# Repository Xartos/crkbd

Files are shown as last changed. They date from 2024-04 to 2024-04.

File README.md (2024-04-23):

# Fork purpose

The purpose of this fork is to replace the audio jack `ST-0277D00-052-142` for the v4 model and replace it with the `PJ-606-6A`

# Corne keyboard

The Corne keyboard is a split keyboard with 3x6 column staggered keys
and 3 thumb keys, based on [Helix](https://github.com/MakotoKurauchi/helix).
Crkbd stands for Corne Keyboard.

v4

## Latest versions
- corne-cherry: for Cherry MX compatible switches

  - v4 Hotswappable ([JP](docs/corne-cherry/v4/buildguide_jp.md)/[EN](docs/corne-cherry/v4/buildguide_en.md))
  - v4 Soldering (will be released)
- corne-chocolate: for Kailh choc v1 and v2 switches
  - v4 Hotswappable ([JP](docs/corne-chocolate/v4/buildguide_jp.md)/[EN](docs/corne-chocolate/v4/buildguide_en.md)):
  - v4 Soldering (will be released)

## Old versions

- corne-classic: for Cherry MX compatible switches 
  - v1 Soldering: ([JP](docs/corne-classic/buildguide_jp.md)/[EN](docs/corne-classic/buildguide_en.md))
- corne-cherry: for Cherry MX compatible switches
  - v2 Hotswappable: ([JP](docs/corne-cherry/v2/buildguide_jp.md)/[EN](docs/corne-cherry/v2/buildguide_en.md))
  - v2 Hotswappable tilting version: ([tilting, JP](docs/corne-cherry/v2/buildguide_tilting_tenting_plate_jp.md)/[tilting, EN](docs/corne-cherry/v2/buildguide_tilting_tenting_plate_en.md)):
  - v3 Hotswappable: ([JP](docs/corne-cherry/v3/buildguide_jp.md)/[EN](docs/corne-cherry/v3/buildguide_en.md))
- corne-chocolate: for Kailh choc v1 switches
  - v2 Hotswappable: ([JP](docs/corne-chocolate/v2/buildguide_jp.md)/[EN](docs/corne-chocolate/v2/buildguide_en.md)):
- corne-light: for easy build with a simple PCB
  - v1 Soldering: ([JP](docs/corne-light/v1/buildguide_jp.md)/[EN](docs/corne-light/v1/buildguide_en.md)):
  - v2 Soldering: ([JP](docs/corne-light/v2/buildguide_low_edition_jp.md)/[EN](docs/corne-light/v2/buildguide_low_edition_en.md)):

## Images

### Cherry
corne-cherry



### Chocolate
corne-chocolate



### Drawing
sketche

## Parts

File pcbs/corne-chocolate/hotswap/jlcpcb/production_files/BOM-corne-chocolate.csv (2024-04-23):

Designator | Footprint | Quantity | Value | LCSC Part #
C1, C2, rC1, rC2 | 0402 | 4 | 27p
C10, C12, C13, C14, C15, C3, C4, C7, C9, rC10, rC12, rC13, rC14, rC15, rC3, rC4, rC7, rC9 | 0402 | 18 | 100n
C11, C6, rC11, rC6 | 0402 | 4 | 10u
C16, C5, C8, rC16, rC5, rC8 | 0402 | 6 | 1u
D1, rD1 | D_SOD-523 | 2 | 1N4148WT | C232841
EXLED1, EXLED2, LED1, LED10, LED11, LED12, LED13, LED14, LED15, LED16, LED17, LED18, LED19, LED2, LED20, LED21, LED3, LED4, LED5, LED6, LED7, LED8, LED9, rEXLED1, rEXLED2, rLED1, rLED10, rLED11, rLED12, rLED13, rLED14, rLED15, rLED16, rLED17, rLED18, rLED19, rLED2, rLED20, rLED21, rLED3, rLED4, rLED5, rLED6, rLED7, rLED8, rLED9 | YS-SK6812MINI-E | 46 | YS-SK6812MINI-E | C5149201
EXSW1, EXSW2, rEXSW1, rEXSW2 | keyswitch_choc12_hotswap_1u_rotary_encoder_ec12 | 4 | RotaryEncoder_Switch | C5333465
F1, rF1 | 0603 | 2 | BSMD0603-050-12V | C2844464
J1, rJ1 | TYPE-C-31-M-13C | 2 | TYPE-C-31-M-13C | C2848620
J2, rJ2 | PJ-606-6A | 2 | PJ-606-6A | C145806
R1, R2, rR1, rR2 | 0402 | 4 | 5.1k
R3, R6, rR3, rR6 | 0402 | 4 | 1k
R4, R5, rR4, rR5 | 0402 | 4 | 27
R7, rR7 | 0402 | 2 | 10k
SMDSW1, SMDSW2, rSMDSW1, rSMDSW2 | TS-1088R-02026 | 4 | TS-1088R-02026 | C455280
SW1, rSW1 | keyswitch_choc12_hotswap_1.5u | 2 | SW_Push | C5333465
SW10, SW11, SW12, SW13, SW14, SW15, SW16, SW17, SW18, SW19, SW2, SW20, SW21, SW3, SW4, SW5, SW6, SW7, SW8, SW9, rSW10, rSW11, rSW12, rSW13, rSW14, rSW15, rSW16, rSW17, rSW18, rSW19, rSW2, rSW20, rSW21, rSW3, rSW4, rSW5, rSW6, rSW7, rSW8, rSW9 | keyswitch_choc12_hotswap_1u | 40 | SW_Push | C5333465
U1, rU1 | QFN-56-1EP_7x7mm_P0.4mm_EP3.2x3.2mm | 2 | RP2040 | C2040
U2, rU2 | SOT-223-3_TabPin2 | 2 | NCP1117LPST33T3G | C146799
U3, rU3 | USON-10_2.5x1.0mm_P0.5mm | 2 | TPD4E05U06DQAR | C138714
U4, rU4 | SOIC-8_5.23x5.23mm_P1.27mm | 2 | W25Q128JVSIQ | C113767
Y1, rY1 | Crystal_SMD_3225-4Pin_3.2x2.5mm | 2 | 12MHz 18pF | C91749
ZD1, rZD1 | D_SOD-523 | 2 | ESD5Z5V0C | C2901325

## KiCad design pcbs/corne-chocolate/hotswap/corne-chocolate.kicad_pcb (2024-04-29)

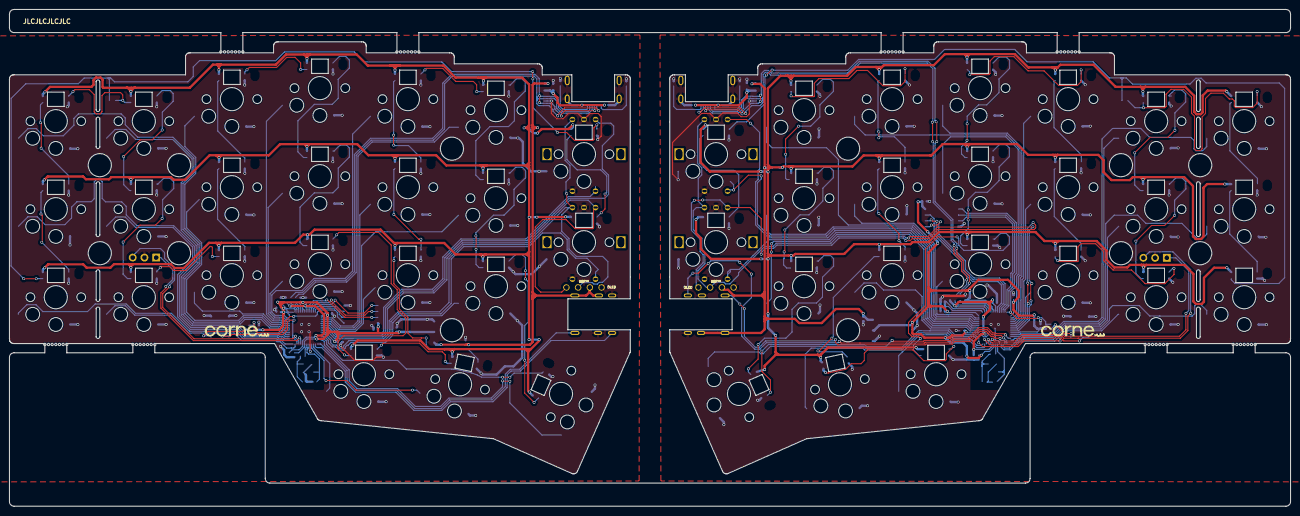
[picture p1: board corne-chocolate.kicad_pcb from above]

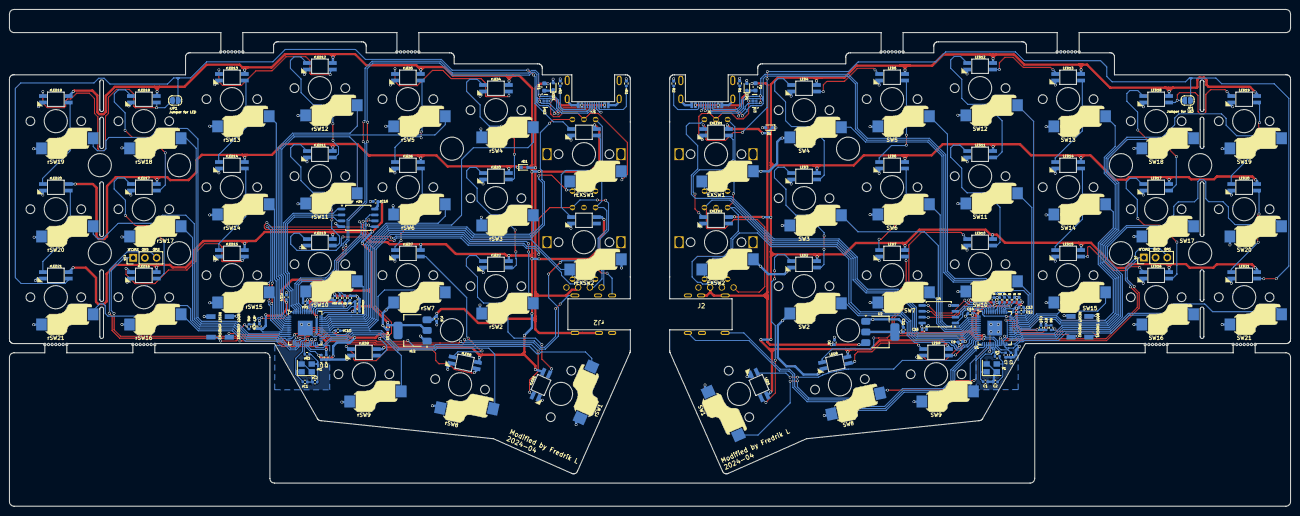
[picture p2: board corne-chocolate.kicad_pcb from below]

Board: 2 copper layers, 277.2 x 107.5 mm, 176 parts (166 on the bottom side), 152 nets.

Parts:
BT1, BT2, BT3, BT4: Breakaway Tabs; Breakaway_Tabs
C1, C2: 27p; C_0402_1005Metric
C3, C4, C7, C9, C10, C12, C13, C14, C15: 100n; C_0402_1005Metric
C5, C8, C16: 1u; C_0402_1005Metric
C6, C11: 10u; C_0402_1005Metric
D1: 1N4148WT; D_SOD-523
EXLED1, EXLED2: YS-SK6812MINI-E
EXSW1, EXSW2: RotaryEncoder_Switch; keyswitch_choc12_hotswap_1u_rotary_encoder_ec12
F1: BSMD0603-050-12V; Fuse_0603_1608Metric
J1: TYPE-C-31-M-13C
J2: PJ-606-6A
J3: Conn_01x04; OLED
J4: Conn_01x03; PinHeader_1x03_P2.54mm_Vertical
JP1: SolderJumper_2_Bridged; SolderJumper-2_P1.3mm_Open_RoundedPad1.0x1.5mm
LED1, LED2, LED3, LED4, LED5, LED6, LED7, LED8, LED9, LED10, LED11, LED12, LED13, LED14, LED15, LED16, LED17, LED18, LED19, LED20, LED21: YS-SK6812MINI-E
R1, R2: 5.1k; R_0402_1005Metric
R3, R6: 1k; R_0402_1005Metric
R4, R5: 27; R_0402_1005Metric
R7: 10k; R_0402_1005Metric
SMDSW1, SMDSW2: TS-1088R-02026
SW1: SW_Push; keyswitch_choc12_hotswap_1.5u
SW2, SW3, SW4, SW5, SW6, SW7, SW8, SW9, SW10, SW11, SW12, SW13, SW14, SW15, SW16, SW17, SW18, SW19, SW20, SW21: SW_Push; keyswitch_choc12_hotswap_1u
U1: RP2040; QFN-56-1EP_7x7mm_P0.4mm_EP3.2x3.2mm
U2: NCP1117LPST33T3G; SOT-223-3_TabPin2
U3: TPD4E05U06DQAR; USON-10_2.5x1.0mm_P0.5mm
U4: W25Q128JVSIQ; SOIC-8_5.23x5.23mm_P1.27mm
Y1: 12MHz 18pF; Crystal_SMD_3225-4Pin_3.2x2.5mm
ZD1: ESD5Z5V0C; D_SOD-523
rBT1, rBT2, rBT3, rBT4: Breakaway Tabs; Breakaway_Tabs
rC1, rC2: 27p; C_0402_1005Metric
rC3, rC4, rC7, rC9, rC10, rC12, rC13, rC14, rC15: 100n; C_0402_1005Metric
rC5, rC8, rC16: 1u; C_0402_1005Metric
rC6, rC11: 10u; C_0402_1005Metric
rD1: 1N4148WT; D_SOD-523
rEXLED1, rEXLED2: YS-SK6812MINI-E
rEXSW1, rEXSW2: RotaryEncoder_Switch; keyswitch_choc12_hotswap_1u_rotary_encoder_ec12
rF1: BSMD0603-050-12V; Fuse_0603_1608Metric
rJ1: TYPE-C-31-M-13C
rJ2: PJ-606-6A
rJ3: Conn_01x04; OLED
rJ4: Conn_01x03; PinHeader_1x03_P2.54mm_Vertical
rJP1: SolderJumper_2_Bridged; SolderJumper-2_P1.3mm_Open_RoundedPad1.0x1.5mm
rLED1, rLED2, rLED3, rLED4, rLED5, rLED6, rLED7, rLED8, rLED9, rLED10, rLED11, rLED12, rLED13, rLED14, rLED15, rLED16, rLED17, rLED18, rLED19, rLED20, rLED21: YS-SK6812MINI-E
rR1, rR2: 5.1k; R_0402_1005Metric
rR3, rR6: 1k; R_0402_1005Metric
rR4, rR5: 27; R_0402_1005Metric
rR7: 10k; R_0402_1005Metric
rSMDSW1, rSMDSW2: TS-1088R-02026
rSW1: SW_Push; keyswitch_choc12_hotswap_1.5u
rSW2, rSW3, rSW4, rSW5, rSW6, rSW7, rSW8, rSW9, rSW10, rSW11, rSW12, rSW13, rSW14, rSW15, rSW16, rSW17, rSW18, rSW19, rSW20, rSW21: SW_Push; keyswitch_choc12_hotswap_1u
rU1: RP2040; QFN-56-1EP_7x7mm_P0.4mm_EP3.2x3.2mm
rU2: NCP1117LPST33T3G; SOT-223-3_TabPin2
rU3: TPD4E05U06DQAR; USON-10_2.5x1.0mm_P0.5mm
rU4: W25Q128JVSIQ; SOIC-8_5.23x5.23mm_P1.27mm
rY1: 12MHz 18pF; Crystal_SMD_3225-4Pin_3.2x2.5mm
rZD1: ESD5Z5V0C; D_SOD-523

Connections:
+1V1: C3.1, C4.1, C5.1, U1.23 (DVDD), U1.45 (VREG_VOUT), U1.50 (DVDD)
+1V1R: rC3.1, rC4.1, rC5.1, rU1.23 (DVDD), rU1.45 (VREG_VOUT), rU1.50 (DVDD)
+3V3: C7.1, C8.1, C9.1, C10.1, C11.1, C12.1, C13.1, C14.1, C15.1, C16.1, R7.2, U1.1 (IOVDD), U1.10 (IOVDD), U1.22 (IOVDD), U1.32 (GPIO21), U1.33 (IOVDD), U1.42 (IOVDD), U1.43 (ADC_AVDD), U1.44 (VREG_IN), U1.48 (USB_VDD), U1.49 (IOVDD), U2.2 (VO), U4.8 (VCC)
+3V3R: rC7.1, rC8.1, rC9.1, rC10.1, rC11.1, rC12.1, rC13.1, rC14.1, rC15.1, rC16.1, rR7.2, rU1.1 (IOVDD), rU1.10 (IOVDD), rU1.22 (IOVDD), rU1.33 (IOVDD), rU1.42 (IOVDD), rU1.43 (ADC_AVDD), rU1.44 (VREG_IN), rU1.48 (USB_VDD), rU1.49 (IOVDD), rU2.2 (VO), rU4.8 (VCC)
+5V: C6.1, D1.2 (A), F1.2, J2.T, J3.3, U2.3 (VI)
+5VR: rC6.1, rD1.2 (A), rF1.2, rJ2.T, rJ3.3, rU2.3 (VI)
/left/D+: J1.A6 (D+), J1.B6 (D+), R4.1, U3.1 (D1+), U3.4 (D2+), U3.7 (NC), U3.10 (NC)
/left/D-: J1.A7 (D-), J1.B7 (D-), R5.2, U3.2 (D1-), U3.5 (D2-), U3.6 (NC), U3.9 (NC)
/left/KEY1: SW1.1, U1.14 (GPIO11)
/left/KEY2: SW2.1, U1.12 (GPIO9)
/left/KEY3: SW3.1, U1.4 (GPIO2)
/left/KEY4: SW4.1, U1.2 (GPIO0)
/left/KEY5: SW5.1, U1.41 (GPIO29_ADC3)
/left/KEY6: SW6.1, U1.3 (GPIO1)
/left/KEY7: SW7.1, U1.5 (GPIO3)
/left/KEY8: SW8.1, U1.18 (GPIO15)
/left/KEY9: SW9.1, U1.17 (GPIO14)
/left/KEY10: SW10.1, U1.40 (GPIO28_ADC2)
/left/KEY11: SW11.1, U1.39 (GPIO27_ADC1)
/left/KEY12: SW12.1, U1.38 (GPIO26_ADC0)
/left/KEY13: SW13.1, U1.35 (GPIO23)
/left/KEY14: SW14.1, U1.36 (GPIO24)
/left/KEY15: SW15.1, U1.37 (GPIO25)
/left/KEY16: SW16.1, U1.27 (GPIO16)
/left/KEY17: SW17.1, U1.29 (GPIO18)
/left/KEY18: SW18.1, U1.31 (GPIO20)
/left/KEY19: SW19.1, U1.34 (GPIO22)
/left/KEY20: SW20.1, U1.30 (GPIO19)
/left/KEY21: SW21.1, U1.28 (GPIO17)
/left/KEYEX1: EXSW1.S2, U1.6 (GPIO4)
/left/KEYEX2: EXSW2.S2, U1.11 (GPIO8)
/left/LED: LED1.4 (DIN), U1.13 (GPIO10)
/left/QSPI_SCLK: U1.52 (QSPI_SCLK), U4.6 (CLK)
/left/QSPI_SD0: U1.53 (QSPI_SD0), U4.5 (DI(IO0))
/left/QSPI_SD1: U1.55 (QSPI_SD1), U4.2 (DO(IO1))
/left/QSPI_SD2: U1.54 (QSPI_SD2), U4.3 (IO2)
/left/QSPI_SD3: U1.51 (QSPI_SD3), U4.7 (IO3)
/left/QSPI_SS: R6.1, R7.1, U1.56 (QSPI_SS), U4.1 (~CS)
/left/RE0A: EXSW1.A, U1.7 (GPIO5)
/left/RE1A: EXSW2.A, J3.1, U1.8 (GPIO6)
/left/REB: EXSW1.B, EXSW2.B, J3.2, U1.9 (GPIO7)
/left/RX: J2.R1, U1.16 (GPIO13)
/left/SWCLK: J4.1, U1.24 (SWCLK)
/left/SWD: J4.3, U1.25 (SWD)
/left/TX: J2.R2, U1.15 (GPIO12)
/right/D+: rJ1.A6 (D+), rJ1.B6 (D+), rR4.1, rU3.1 (D1+), rU3.4 (D2+), rU3.7 (NC), rU3.10 (NC)
/right/D-: rJ1.A7 (D-), rJ1.B7 (D-), rR5.2, rU3.2 (D1-), rU3.5 (D2-), rU3.6 (NC), rU3.9 (NC)
/right/KEY1: rSW1.1, rU1.30 (GPIO19)
/right/KEY2: rSW2.1, rU1.34 (GPIO22)
/right/KEY3: rSW3.1, rU1.38 (GPIO26_ADC0)
/right/KEY4: rSW4.1, rU1.39 (GPIO27_ADC1)
/right/KEY5: rSW5.1, rU1.3 (GPIO1)
/right/KEY6: rSW6.1, rU1.40 (GPIO28_ADC2)
/right/KEY7: rSW7.1, rU1.31 (GPIO20)
/right/KEY8: rSW8.1, rU1.28 (GPIO17)
/right/KEY9: rSW9.1, rU1.27 (GPIO16)
/right/KEY10: rSW10.1, rU1.41 (GPIO29_ADC3)
/right/KEY11: rSW11.1, rU1.2 (GPIO0)
/right/KEY12: rSW12.1, rU1.4 (GPIO2)
/right/KEY13: rSW13.1, rU1.5 (GPIO3)
/right/KEY14: rSW14.1, rU1.6 (GPIO4)
/right/KEY15: rSW15.1, rU1.7 (GPIO5)
/right/KEY16: rSW16.1, rU1.29 (GPIO18)
/right/KEY17: rSW17.1, rU1.17 (GPIO14)
/right/KEY18: rSW18.1, rU1.12 (GPIO9)
/right/KEY19: rSW19.1, rU1.11 (GPIO8)
/right/KEY20: rSW20.1, rU1.14 (GPIO11)
/right/KEY21: rSW21.1, rU1.18 (GPIO15)
/right/KEYEX1: rEXSW1.S2, rU1.37 (GPIO25)
/right/KEYEX2: rEXSW2.S2, rU1.35 (GPIO23)
/right/LED: rLED1.4 (DIN), rU1.13 (GPIO10)
/right/QSPI_SCLK: rU1.52 (QSPI_SCLK), rU4.6 (CLK)
/right/QSPI_SD0: rU1.53 (QSPI_SD0), rU4.5 (DI(IO0))
/right/QSPI_SD1: rU1.55 (QSPI_SD1), rU4.2 (DO(IO1))
/right/QSPI_SD2: rU1.54 (QSPI_SD2), rU4.3 (IO2)
/right/QSPI_SD3: rU1.51 (QSPI_SD3), rU4.7 (IO3)
/right/QSPI_SS: rR6.1, rR7.1, rU1.56 (QSPI_SS), rU4.1 (~CS)
/right/RE0A: rEXSW1.A, rU1.36 (GPIO24)
/right/RE1A: rEXSW2.A, rJ3.1, rU1.8 (GPIO6)
/right/REB: rEXSW1.B, rEXSW2.B, rJ3.2, rU1.9 (GPIO7)
/right/RX: rJ2.R2, rU1.16 (GPIO13)
/right/SWCLK: rJ4.1, rU1.24 (SWCLK)
/right/SWD: rJ4.3, rU1.25 (SWD)
/right/TX: rJ2.R1, rU1.15 (GPIO12)
GND: C1.2, C2.2, C3.2, C4.2, C5.2, C6.2, C7.2, C8.2, C9.2, C10.2, C11.2, C12.2, C13.2, C14.2, C15.2, C16.2, EXLED1.3 (VSS), EXLED2.3 (VSS), EXSW1.C, EXSW1.S1, EXSW2.C, EXSW2.S1, J1.A1 (GND), J1.A12 (GND), J1.B1 (GND), J1.B12 (GND), J1.S1 (SHIELD), J2.S, J3.4, J4.2, LED1.3 (VSS), LED2.3 (VSS), LED3.3 (VSS), LED4.3 (VSS), LED5.3 (VSS), LED6.3 (VSS), LED7.3 (VSS), LED8.3 (VSS), LED9.3 (VSS), LED10.3 (VSS), LED11.3 (VSS), LED12.3 (VSS), LED13.3 (VSS), LED14.3 (VSS), LED15.3 (VSS), LED16.3 (VSS), LED17.3 (VSS), LED18.3 (VSS), LED19.3 (VSS), LED20.3 (VSS), LED21.3 (VSS), R1.1, R2.1, SMDSW1.1, SMDSW2.1, SW1.2, SW2.2, SW3.2, SW4.2, SW5.2, SW6.2, SW7.2, SW8.2, SW9.2, SW10.2, SW11.2, SW12.2, SW13.2, SW14.2, SW15.2, SW16.2, SW17.2, SW18.2, SW19.2, SW20.2, SW21.2, U1.19 (TESTEN), U1.57 (GND), U2.1 (GND), U3.3 (GND), U3.8 (GND), U4.4 (GND), Y1.2, Y1.4, ZD1.2 (A)
GNDR: rC1.2, rC2.2, rC3.2, rC4.2, rC5.2, rC6.2, rC7.2, rC8.2, rC9.2, rC10.2, rC11.2, rC12.2, rC13.2, rC14.2, rC15.2, rC16.2, rEXLED1.3 (VSS), rEXLED2.3 (VSS), rEXSW1.C, rEXSW1.S1, rEXSW2.C, rEXSW2.S1, rJ1.A1 (GND), rJ1.A12 (GND), rJ1.B1 (GND), rJ1.B12 (GND), rJ1.S1 (SHIELD), rJ2.S, rJ3.4, rJ4.2, rLED1.3 (VSS), rLED2.3 (VSS), rLED3.3 (VSS), rLED4.3 (VSS), rLED5.3 (VSS), rLED6.3 (VSS), rLED7.3 (VSS), rLED8.3 (VSS), rLED9.3 (VSS), rLED10.3 (VSS), rLED11.3 (VSS), rLED12.3 (VSS), rLED13.3 (VSS), rLED14.3 (VSS), rLED15.3 (VSS), rLED16.3 (VSS), rLED17.3 (VSS), rLED18.3 (VSS), rLED19.3 (VSS), rLED20.3 (VSS), rLED21.3 (VSS), rR1.1, rR2.1, rSMDSW1.1, rSMDSW2.1, rSW1.2, rSW2.2, rSW3.2, rSW4.2, rSW5.2, rSW6.2, rSW7.2, rSW8.2, rSW9.2, rSW10.2, rSW11.2, rSW12.2, rSW13.2, rSW14.2, rSW15.2, rSW16.2, rSW17.2, rSW18.2, rSW19.2, rSW20.2, rSW21.2, rU1.19 (TESTEN), rU1.32 (GPIO21), rU1.57 (GND), rU2.1 (GND), rU3.3 (GND), rU3.8 (GND), rU4.4 (GND), rY1.2, rY1.4, rZD1.2 (A)
unnamed: C2.1, R3.1, Y1.3
unnamed: D1.1 (K), EXLED1.1 (VDD), EXLED2.1 (VDD), LED1.1 (VDD), LED2.1 (VDD), LED3.1 (VDD), LED4.1 (VDD), LED5.1 (VDD), LED6.1 (VDD), LED7.1 (VDD), LED8.1 (VDD), LED9.1 (VDD), LED10.1 (VDD), LED11.1 (VDD), LED12.1 (VDD), LED13.1 (VDD), LED14.1 (VDD), LED15.1 (VDD), LED16.1 (VDD), LED17.1 (VDD), LED18.1 (VDD), LED19.1 (VDD), LED20.1 (VDD), LED21.1 (VDD)
unnamed: EXLED1.4 (DIN), JP1.2 (B), LED21.2 (DOUT)
unnamed: EXLED1.2 (DOUT), EXLED2.4 (DIN)
unnamed: J1.A5 (CC1), R1.2
unnamed: J1.B5 (CC2), R2.2
unnamed: JP1.1 (A), LED18.2 (DOUT), LED19.4 (DIN)
unnamed: LED1.2 (DOUT), LED2.4 (DIN)
unnamed: LED2.2 (DOUT), LED3.4 (DIN)
unnamed: LED3.2 (DOUT), LED4.4 (DIN)
unnamed: LED4.2 (DOUT), LED5.4 (DIN)
unnamed: LED5.2 (DOUT), LED6.4 (DIN)
unnamed: LED6.2 (DOUT), LED7.4 (DIN)
unnamed: LED7.2 (DOUT), LED8.4 (DIN)
unnamed: LED8.2 (DOUT), LED9.4 (DIN)
unnamed: LED9.2 (DOUT), LED10.4 (DIN)
unnamed: LED10.2 (DOUT), LED11.4 (DIN)
unnamed: LED11.2 (DOUT), LED12.4 (DIN)
unnamed: LED12.2 (DOUT), LED13.4 (DIN)
unnamed: LED13.2 (DOUT), LED14.4 (DIN)
unnamed: LED14.2 (DOUT), LED15.4 (DIN)
unnamed: LED15.2 (DOUT), LED16.4 (DIN)
unnamed: LED16.2 (DOUT), LED17.4 (DIN)
unnamed: LED17.2 (DOUT), LED18.4 (DIN)
unnamed: LED19.2 (DOUT), LED20.4 (DIN)
unnamed: LED20.2 (DOUT), LED21.4 (DIN)
unnamed: R6.2, SMDSW1.2
unnamed: SMDSW2.2, U1.26 (RUN)
unnamed: R5.1, U1.46 (USB_DM)
unnamed: R4.2, U1.47 (USB_DP)
unnamed: C1.1, U1.20 (XIN), Y1.1
unnamed: R3.2, U1.21 (XOUT)
unnamed: rC2.1, rR3.1, rY1.3
unnamed: rD1.1 (K), rEXLED1.1 (VDD), rEXLED2.1 (VDD), rLED1.1 (VDD), rLED2.1 (VDD), rLED3.1 (VDD), rLED4.1 (VDD), rLED5.1 (VDD), rLED6.1 (VDD), rLED7.1 (VDD), rLED8.1 (VDD), rLED9.1 (VDD), rLED10.1 (VDD), rLED11.1 (VDD), rLED12.1 (VDD), rLED13.1 (VDD), rLED14.1 (VDD), rLED15.1 (VDD), rLED16.1 (VDD), rLED17.1 (VDD), rLED18.1 (VDD), rLED19.1 (VDD), rLED20.1 (VDD), rLED21.1 (VDD)
unnamed: rEXLED1.4 (DIN), rJP1.2 (B), rLED21.2 (DOUT)
unnamed: rEXLED1.2 (DOUT), rEXLED2.4 (DIN)
unnamed: rJ1.A5 (CC1), rR1.2
unnamed: rJ1.B5 (CC2), rR2.2
unnamed: rJP1.1 (A), rLED18.2 (DOUT), rLED19.4 (DIN)
unnamed: rLED1.2 (DOUT), rLED2.4 (DIN)
unnamed: rLED2.2 (DOUT), rLED3.4 (DIN)
unnamed: rLED3.2 (DOUT), rLED4.4 (DIN)
unnamed: rLED4.2 (DOUT), rLED5.4 (DIN)
unnamed: rLED5.2 (DOUT), rLED6.4 (DIN)
unnamed: rLED6.2 (DOUT), rLED7.4 (DIN)
unnamed: rLED7.2 (DOUT), rLED8.4 (DIN)
unnamed: rLED8.2 (DOUT), rLED9.4 (DIN)
unnamed: rLED9.2 (DOUT), rLED10.4 (DIN)
unnamed: rLED10.2 (DOUT), rLED11.4 (DIN)
unnamed: rLED11.2 (DOUT), rLED12.4 (DIN)
unnamed: rLED12.2 (DOUT), rLED13.4 (DIN)
unnamed: rLED13.2 (DOUT), rLED14.4 (DIN)
unnamed: rLED14.2 (DOUT), rLED15.4 (DIN)
unnamed: rLED15.2 (DOUT), rLED16.4 (DIN)
unnamed: rLED16.2 (DOUT), rLED17.4 (DIN)
unnamed: rLED17.2 (DOUT), rLED18.4 (DIN)
unnamed: rLED19.2 (DOUT), rLED20.4 (DIN)
unnamed: rLED20.2 (DOUT), rLED21.4 (DIN)
unnamed: rR6.2, rSMDSW1.2
unnamed: rSMDSW2.2, rU1.26 (RUN)
unnamed: rR5.1, rU1.46 (USB_DM)
unnamed: rR4.2, rU1.47 (USB_DP)
unnamed: rC1.1, rU1.20 (XIN), rY1.1
unnamed: rR3.2, rU1.21 (XOUT)
VBUS: F1.1, J1.A4 (VBUS), J1.A9 (VBUS), J1.B4 (VBUS), J1.B9 (VBUS), ZD1.1 (K)
VBUSR: rF1.1, rJ1.A4 (VBUS), rJ1.A9 (VBUS), rJ1.B4 (VBUS), rJ1.B9 (VBUS), rZD1.1 (K)

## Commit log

2024-04-23 Kicad automatically updated footprints
2024-04-23 Added PJ-606-6A footprint
2024-04-23 Updated pcb for corne-chocolate to use PJ-606-6A audio jack
    [corne-chocolate.kicad_sch, left.kicad_sch, right.kicad_sch]
2024-04-23 Updated JLCPCB production files for corne-chocolate
    [BOM-corne-chocolate.csv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]
2024-04-29 Moved VIAs in compliance with JLCPCB engineers
    [corne-chocolate.kicad_pcb]
